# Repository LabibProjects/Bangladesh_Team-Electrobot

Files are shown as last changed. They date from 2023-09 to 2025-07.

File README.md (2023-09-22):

# Engineering materials | Team Electrobots | Bangladesh
----

This repository contains engineering materials of a self-driven vehicle's model participating in the WRO Future Engineers competition in the season 2023.

----
## Team Members:

- Zuniyed Hossain Bhuiyan
- L.M Mahir Labib
- Tanvir Rahman Saad
----

## Contents

* `t-photos` contains 2 photos of the team (an official one and one funny photo with all team members)
* `v-photos` contains 6 photos of the vehicle (from every side, from top and bottom)
* `video` contains the video.md file with the link to a video where driving demonstration exists
* `schemes` contains one or several schematic diagrams in form of JPEG, PNG or PDF of the electromechanical components illustrating all the elements (electronic components and motors) used in the vehicle and how they connect to each other.
* `src` contains code of control software for all components which were programmed to participate in the competition
* `models` is for the files for models used by 3D printers, laser cutting machines and CNC machines to produce the vehicle elements. If there is nothing to add to this location, the directory can be removed.
* `Mobility Management` contains details of the movement management of the bot, chasis design,power,torque etc.
* `Power and Sense Management` contains discussion about the power supply and sensors used in the vehicle.
* `Obstacle Management` include the strategy for the vehicle to negotiate the obstacle course for all the challenges.
* `other` is for other files which can be used to understand how to prepare the vehicle for the competition. It may include documentation how to connect to a SBC/SBM and upload files there, datasets, hardware specifications, communication protocols descriptions etc. If there is nothing to add to this location, the directory can be removed.
----
## Introduction 

The "Electrobot Autonomous Vehicle" project is an innovative endeavor that combines cutting-edge technologies to create a self-guided vehicle capable of intelligent navigation. This repository serves as a central hub for all essential files, documentation, and information related to the project.The project utilizes an ESP32-based development board known as the "JRC Board." This versatile and powerful board forms the foundation of the vehicle's control system.To enable advanced object recognition capabilities, the vehicle is equipped with a DFROBOT Gravity Huskylens, an AI-based camera. This camera plays a crucial role in identifying and interacting with objects in the vehicle's environment.The project incorporates an MPU-6050 gyroscope and accelerometer sensor. This sensor suite provides critical data for lap counting and monitoring angular velocity. The angular velocity measurements are given in millivolts per degree per second (mV/deg/s).

## Electric System design: 

We have choosed the parts very carefully after several hours of R&D

+ JRC Board: An ESP32 based development board (Made in Bangladesh)
+ Huskylens: Embedded Vision Sensor
+ DFROBOT URM09 Ultrasonic Sensors
+ 12v 100 RPM DC Geared Motor
+ MG-996R 10 kg Servo Motor
+ L298N Motor Driver
+ Mpu 6050 gyroscope sensor
+ 2x MP1584 Buck Converter
+ XL 4015 Boost Converter
+ 3s Lipo Battery 11.1v 

----
## Software Setup Procedure

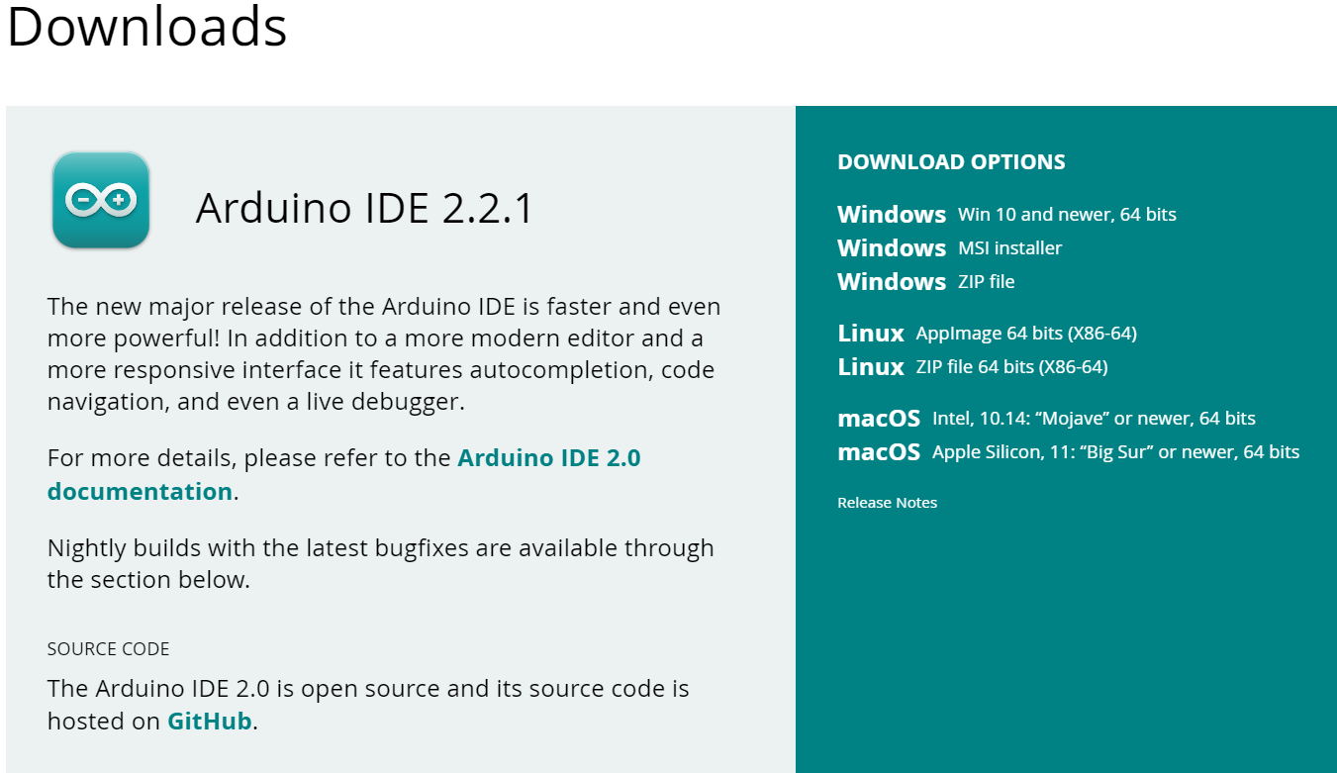
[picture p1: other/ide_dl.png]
ide_dl

- At first, we will have to download and install the most up-to-date version of the Arduino IDE on our computer. We can find the software at arduino.cc/en/Main/Software.

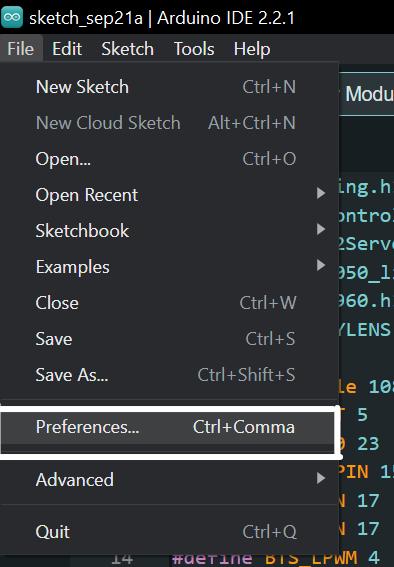
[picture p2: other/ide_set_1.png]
ide_set_1
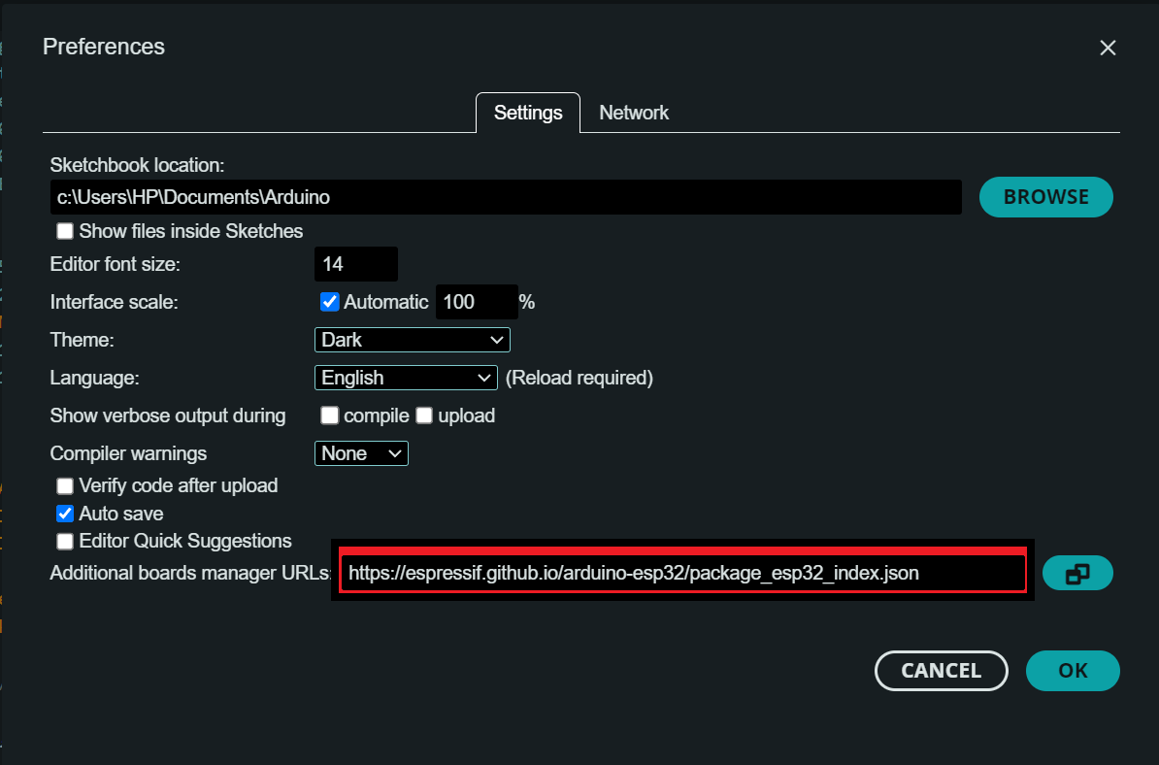
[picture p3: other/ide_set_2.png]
ide_set_2
   |  
- In our Arduino IDE, we need to go to File > Preferences, and then enter the following into the 'Additional Board Manager URLs' field. Finally, we click OK.
`https://espressif.github.io/arduino-esp32/package_esp32_index.json`

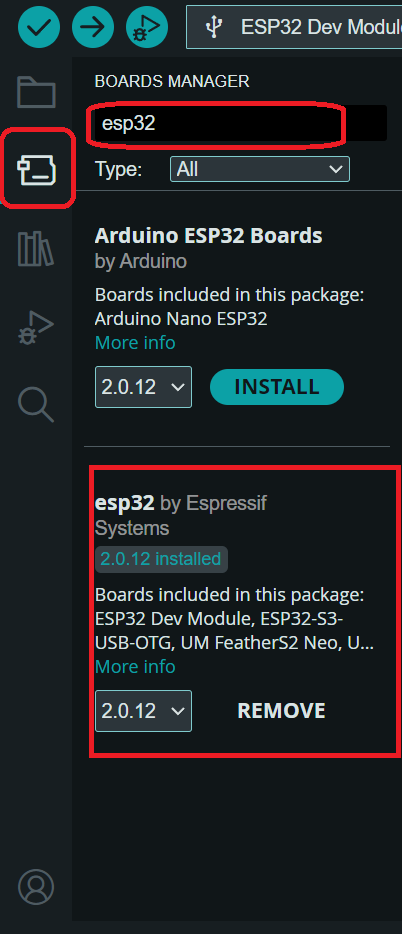
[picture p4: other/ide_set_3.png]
ide_set_3

- On the left side of our IDE we will have to open our Board Manager . Press install button for the "ESP32 by Espressif Systems".

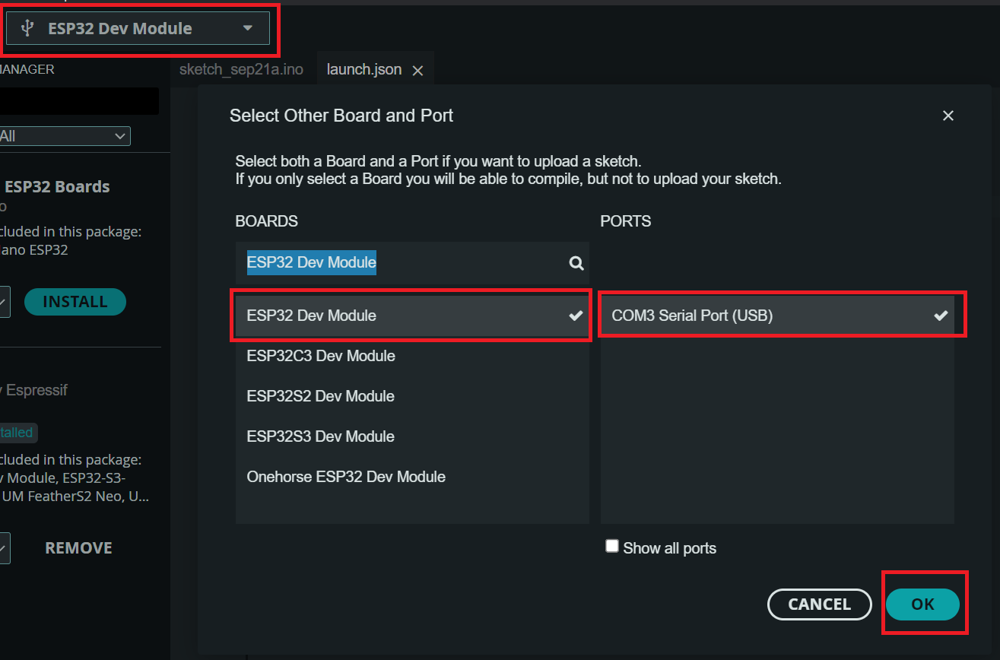
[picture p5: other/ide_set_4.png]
ide_set_4

- Now we will have to select our board so on the upper left side of IDE we will select our board, "ESP32 DEV MODULE" then we will select our prefered board where we have connected our JRC board.

ide_set_5
- Finally our task is to upload the code clicking "→" icon we upload our code. 

- Now we can turn on the toggle switch after placing robot on track and it will start doing the laps.

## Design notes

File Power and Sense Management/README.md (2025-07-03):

**Power and Sense Management**
====
In the realm of robotics, effective power and sense management is the linchpin of our robot's performance. Our cutting-edge system ensures optimal resource allocation, revolutionizing how robots interact with their surroundings.

## 1. Power Management: 

Power
">

   At first from lithium ion cell we are fetching 3.7v and being 12v by XL60009. then HW-411A LM2596 are cosuming power to 3.3v for the sensor e.g. Pi Camera, SR04 ultrasonic sensor and gyroscope MPU 6050.  Laterby we are suplying 5v to servo 12v to BTS7960 and motor being powered to.
## 2. Sensors: 
Sensor

- #### **Ultrasonic Sensor:**
   

   The SR04 is an ultrasonic distance sensor used for measuring distances. We're powering it with a stable 5V supply obtained from an HW-411A LM2596 voltage regulator connected to an 11.1V LiPo battery. This setup ensures reliable distance measurements and efficient power management for our robot.

- #### **Pi Camera:**
  

The Raspberry Pi Camera is a high-definition vision module capable of capturing images and streaming video, commonly used in robotics and computer vision applications. In our configuration, we use the Raspberry Pi Camera Module connected to a Raspberry Pi 4B, which serves as the core processing unit for advanced image processing tasks. The camera interfaces directly with the Raspberry Pi via the CSI (Camera Serial Interface) port, enabling high-speed data transfer. 
- #### **Gyroscope:**
  MPU

The MPU6050 is a popular gyroscope and accelerometer sensor used for motion sensing and orientation tracking in various applications, including robotics and motion-controlled devices. In our setup, the MPU6050 is powered by a 5V supply sourced from an ESP32 Dev Board, which itself receives power from an HW-411A LM2596 voltage regulator. This HW-411A LM2596 regulator is connected to an XL60009 module, and the entire system is powered by an 3.7V lithium ion cell.

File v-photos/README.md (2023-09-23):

Vehicle's photos
====

This directory must contain 6 photos of the vehicle (from every side, from top and bottom)

## File perspective description

   - `front.jpeg`: Front view: L298N motor driver, a battery unit and front steering axles.
   - `bottom.jpeg`: Bottom view: main motor functions
   - `top.jpeg`: Top view: PCB, JRC Board, huskylens, boost converter, gyroscope, sonar sensor and servo
   - `bottom.jpeg`: Bottom view: aluminium base plate
   - `left.jpeg`: Left view: Wheels and front steering axel from left perspective
   - `right.jpeg`: Right view: Wheels and front steering axel from left perspective

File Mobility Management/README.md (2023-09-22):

Mobility Management
====
In the realm of mobility management for our vehicle, we meticulously select and implement motors based on engineering principles like speed, torque, and power, while also considering chassis design and component mounting for optimal performance. Assembly instructions and 3D CAD files are available for easy part fabrication.

# Motor Selection and Implementation:
### 1. Motor Selection:
   - We carefully considered various factors like vehicle weight, desired speed, and torque requirements to make the right choice of motors. For our obstacle-avoiding bot, we opted for DC motors and servo motors to ensure precise control.
   - We performed calculations to determine the necessary torque, taking into account the bot's weight, wheel size, and the maximum slope it might encounter.
   - We also took into consideration the power supply and voltage requirements of the motors we selected.

### 2. Motor Controller:
   - We chose an appropriate motor controller, the BTS7960, to effectively control the motors.
   - We made sure that the motor controller was compatible with our microcontroller or control board.

### 3. Implementation:
   - We connected the motors to the motor controller and then linked the controller to the JRC Board.

# Chassis Design and Selection:
### 1. Chassis Material: Plastic with a steel alloy base.
### 2. Chassis Shape:
   - We designed the chassis to accommodate all the components, including motors, sensors, and the power source.
   - We ensured that the chassis provided adequate ground clearance and stability.

### 3. Mounting Components:
   - We carefully planned the layout of components on the chassis to ensure an even weight distribution and easy access for maintenance.
   - Subsequently, we securely mounted the motors, ultrasonic sensor, gyroscope, JRC booster, Husylens, and the power supply.

### 4. Engineering Principles:
   - We calculated the center of mass to maintain stability.
   - We took into account the wheelbase and track width to optimize maneuverability.
   - We paid attention to proper weight distribution to prevent tipping.

# Building and Assembly Instructions:
### 1. Step-by-Step Assembly:
   - We provided clear, step-by-step instructions for assembling the vehicle, starting from the chassis and moving on to component mounting.
   - Additionally, we included wiring diagrams to assist in connecting motors, sensors, and controllers.

### 2. 3D Printing Parts:
   - WE designed Sonar mount and wheels for better optimization in Auodesk Fusion360.
   - We also included instructions for printing these parts, specifying recommended materials and settings.

### 3. Testing and Calibration:
   - We explained how to calibrate the vehicle's sensors and motor controllers.
   - We provided guidance on testing the vehicle's basic movements and its ability to detect obstacles effectively.

### 4. Safety Considerations:
   - We emphasized safety precautions when working with motors, electronics, and power sources, ensuring that safety was a top priority throughout the project.

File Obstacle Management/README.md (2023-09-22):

Obstacle Management
====
To create a bot that can navigate a track with obstacles using an ultrasonic sensor and gyroscope, you'll need to implement a control algorithm that allows the bot to detect obstacles, stop when necessary, and navigate around them. Below is a high-level strategy along with some pseudo code to help you get started.
## **Strategy:**

1. Initialize the bot with the necessary sensors and gyroscope.
2. Start the bot and begin the first lap.
3. Continuously monitor the ultrasonic sensor to detect obstacles in the path.
4. Use the gyroscope to maintain the bot's direction and orientation.
5. When an obstacle is detected:
   - Determine the direction of the obstacle (left or right).
   - Turn the bot in the opposite direction to avoid the obstacle.
   - Resume forward movement once the obstacle is clear.
6. Continue navigating the track and detecting obstacles until completing three laps.

Additionally, we need to fine-tune the values and thresholds for obstacle detection and the turning angles based on your bot's characteristics and the track layout. Testing and iterating on the code and parameters will be crucial to ensure your bot successfully completes the laps while avoiding obstacles.

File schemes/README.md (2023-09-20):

Electrical Systems Design
====

Folder contains the electrical design schematics,pcb design,block diagram designed in EasyEDA and Altium Designer

## Description of Electrical Systems Design

   - `Schematic.pdf`: This is the schematic's pdf file, which is suitable for printing..
   - `PCB_3d_model.pdf`: This is the 3d version of the PCB, which helps understanding the I/O pinouts.
   - `PCB.pdf`: This is the pdf of the pcb.
   - `pcb_pinouts.png`: To help understanding the pinouts of the PCB.
   - `System_Management`: Diagram of the overall system.
   - `Block_Diagram`: Block Diagram of the system.

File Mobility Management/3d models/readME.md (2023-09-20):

Custom 3D Printed Design 
====
All of our robot's crucial components were created through 3D printing after being meticulously designed and modeled using Autodesk Fusion 360.

## Description of 3D Printable Files

   - `20 degree angled URM09 sonar mount.stl`: This model serves as a mounting solution for precisely positioning our front two URM09 sensors at a 20-degree angle.
   - `Front Wheel.stl`: To make turn more precisely we designed custom wheel .

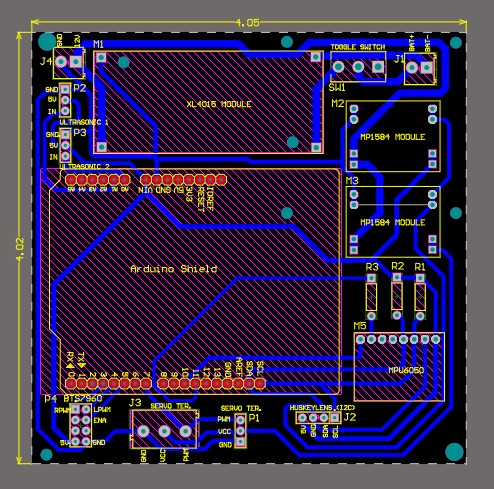
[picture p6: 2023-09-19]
schemes/pcb_pinouts.jpeg

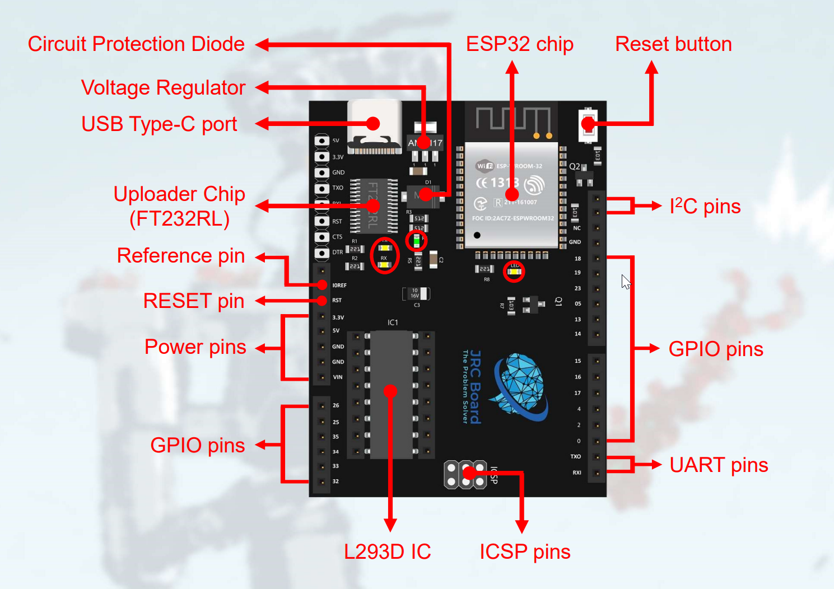
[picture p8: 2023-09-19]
schemes/JRC_board_pinouts.png

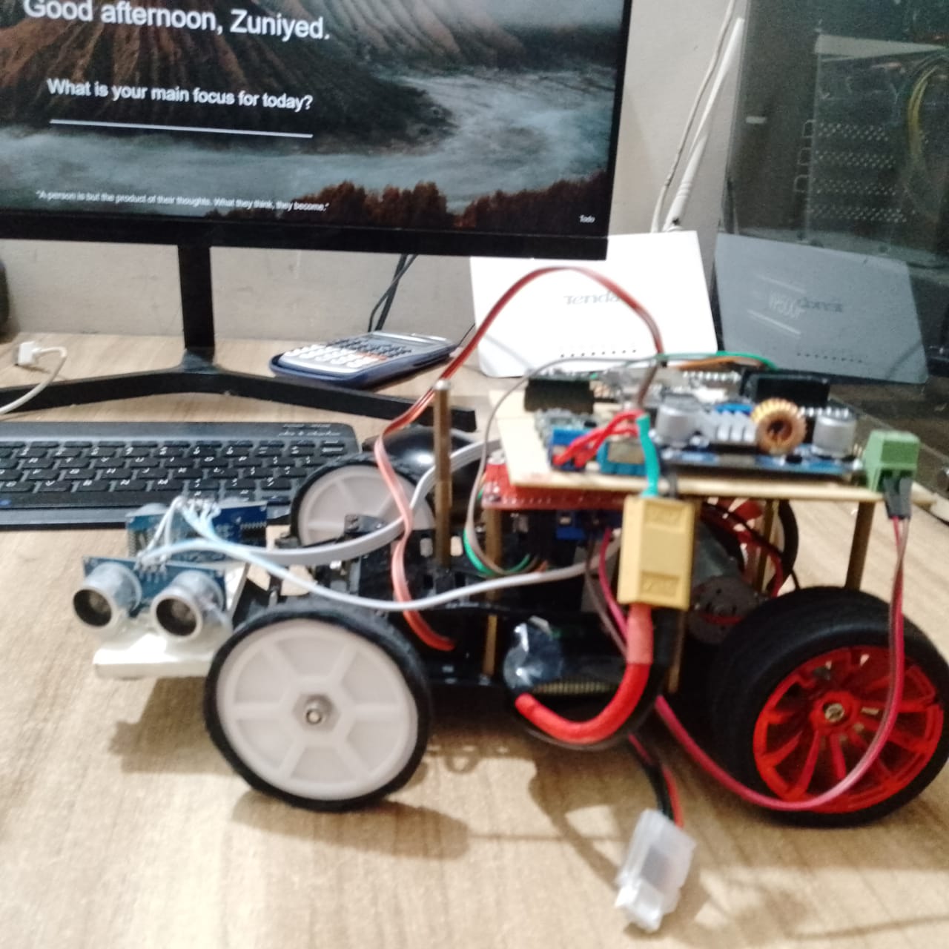
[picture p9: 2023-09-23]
v-photos/left.jpeg

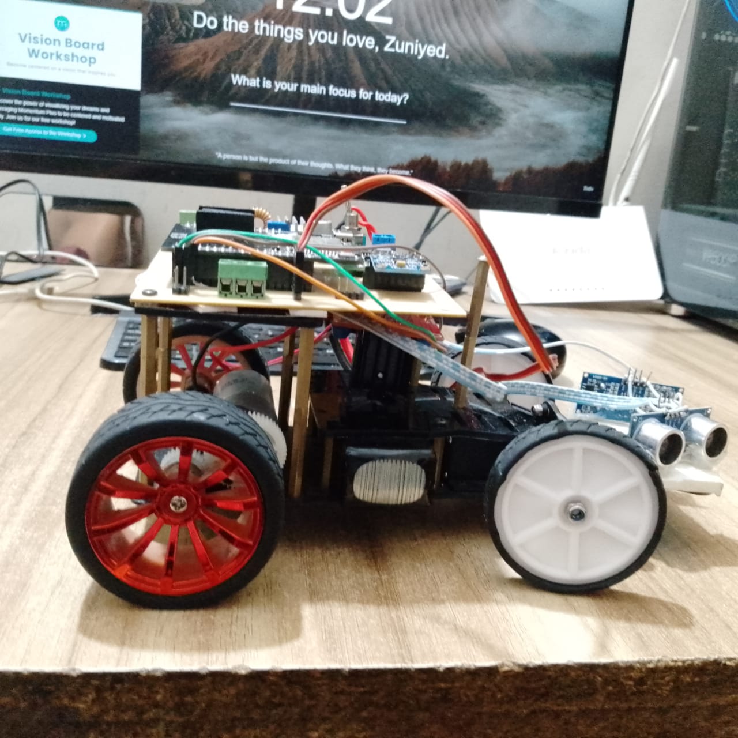
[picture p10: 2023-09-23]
v-photos/right.jpeg

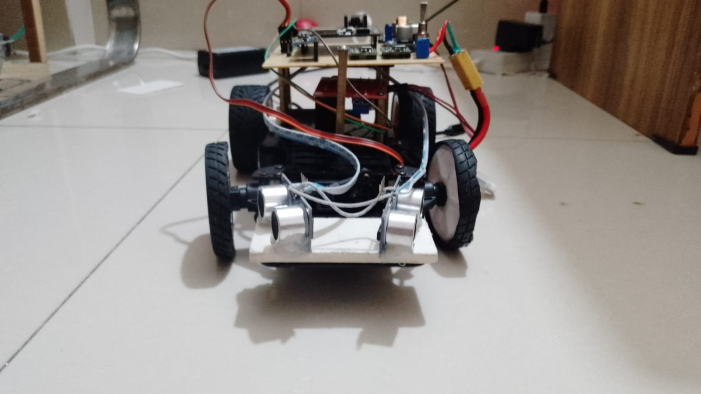
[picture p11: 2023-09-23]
v-photos/front.jpeg

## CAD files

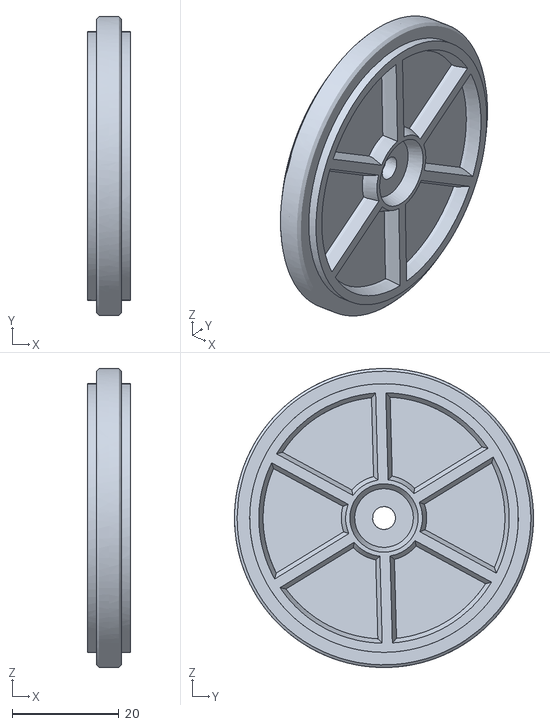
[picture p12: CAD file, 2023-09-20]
Mobility Management/3d models/Front Wheel.stl
8.00 x 56.0 x 56.0

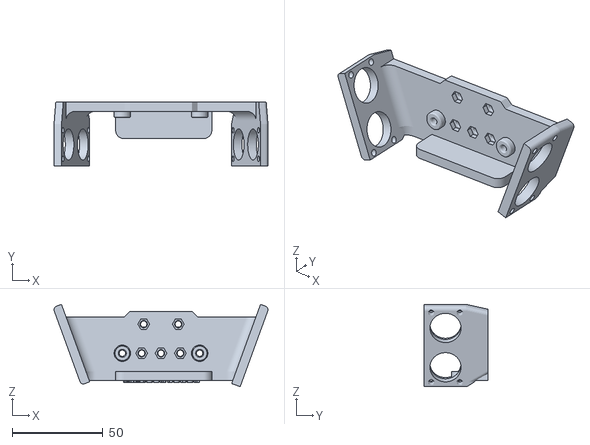
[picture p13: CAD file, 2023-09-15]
Mobility Management/3d models/20 degree angled URM09 sonar mount.stl
117.6 x 35.0 x 45.3

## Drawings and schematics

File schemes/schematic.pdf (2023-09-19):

Power Section | Sensors and Camera

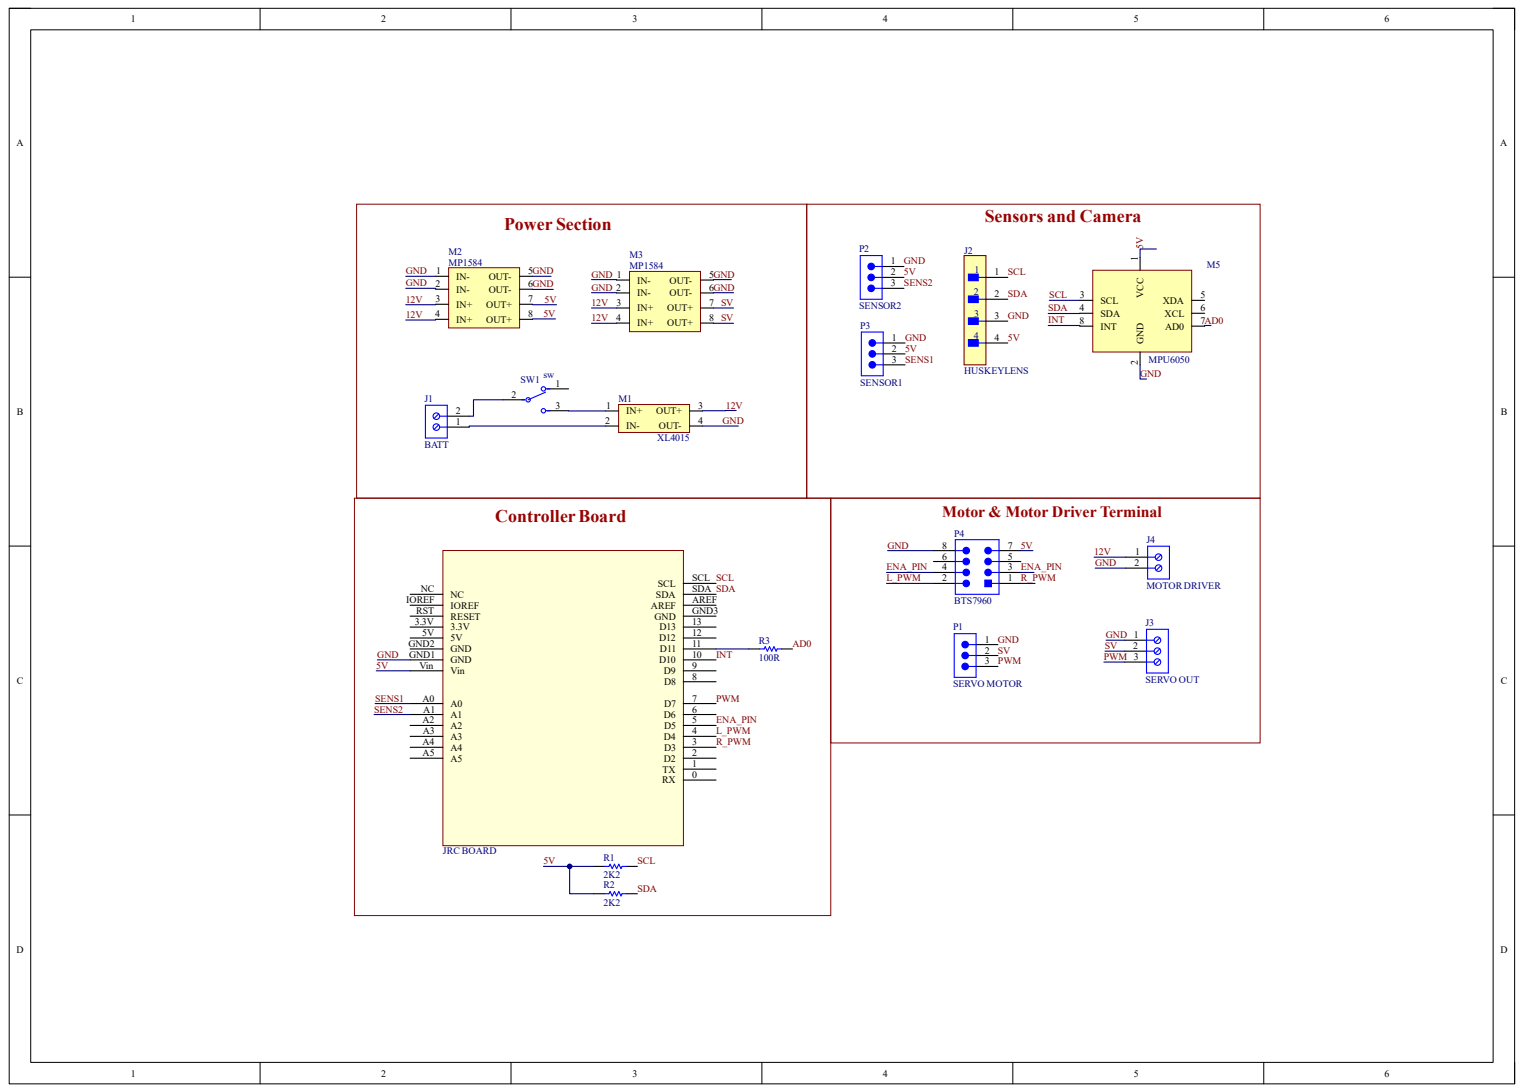
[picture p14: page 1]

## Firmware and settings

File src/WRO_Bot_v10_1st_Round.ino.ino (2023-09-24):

  #include "Wire.h"
  #include <MPU6050_light.h>
  #include <ESP32Servo.h>
  #include <NewPing.h>
  #include "HUSKYLENS.h"

  #define dbg 1
  #define turningAcceleration 8  //8
  #define distanceTolarance 8
  #define testClearance 44
  #define minClearance 40
  #define withThreshold 80
  #define narrowThreshold 35

  #define middlePos 70
  #define leftMax 40 //30 //20
  #define rightMax 100 //100 //120
  
  #define carSpeed 200
  #define turningDelay 500

  #define stopTime 2000
  #define endAngle 1030

  #define servoPin 15
  #define startSW 14

  #define rightSonarTrig 25  
  #define rightSonarEcho 26  
  #define leftSonarTrig 33
  #define leftSonarEcho 32
  #define maxDistance 200 // Maximum distance we want to ping for (in centimeters). Maximum sensor distance is rated at 400-500cm.

  #define mPin1 4
  #define mPin2 2
  #define enPin 17
  #define ledPin 13

  MPU6050 mpu(Wire);
  HUSKYLENS huskylens;

  Servo servo;  // create servo object to control a servo

  NewPing rightSonar(rightSonarTrig, rightSonarEcho, maxDistance);  // NewPing setup of pins and maximum distance.
  NewPing leftSonar(leftSonarTrig, leftSonarEcho, maxDistance);     // NewPing setup of pins and maximum distance.

  uint16_t leftSonarVal = 0, rightSonarVal = 0;
  uint16_t leftClearance = 0, rightClearance = 0, totalDistance = 0;
  int yawAngle = 0, rawYaw = 0;
  uint8_t startPosition = 1, lapsCount = 0;
  int pos = middlePos;
  bool gotMaxDistance = 0;
  int  tempLeftClearance = 0, tempRightClearance = 0;
  int currentTotalWidth = 0;
  bool narrowImportant = 0;
  bool blue =0, orange = 0, colorStts = 1;
  uint8_t color = 0;
  unsigned long currentTime = 0, prevTime = 0;
  unsigned long currentTime2 = 0, prevTime2 = 0;
  bool lapStts = 0;

  void setup() {
    if(dbg) Serial.begin(115200);
    
    mpuInit();

    servo.attach(servoPin);  // attaches the servo on pin 9 to the servo object
    servo.write(middlePos);
    delay(200);

    pinMode(mPin1, OUTPUT); pinMode(mPin2, OUTPUT);
    pinMode(enPin, OUTPUT); pinMode(ledPin, OUTPUT);
    pinMode(startSW, INPUT_PULLUP);
    digitalWrite(mPin1, 0); digitalWrite(mPin2, 0); digitalWrite(enPin, 0);

    calculateClearance();
    HuskyInit();

    while(digitalRead(startSW)){ 
      digitalWrite(ledPin, 0); delay(100);
      digitalWrite(ledPin, 1); delay(100);
      }
    forward(carSpeed);
  }

  void loop() {
    leftSonarVal = leftSonar.ping_cm(); 
    rightSonarVal = rightSonar.ping_cm();
    currentTotalWidth = leftSonarVal + rightSonarVal;

    color = getHusky();

    if(leftSonarVal < 5 || leftSonarVal > 100) { leftSonarVal = maxDistance; } 
    if(color == 1) {
      if(gotMaxDistance == 0 ) {
         gotMaxDistance =1; startPosition = 0; 
         if(leftClearance > narrowThreshold) narrowImportant = 1;
        } 
      }
    if(rightSonarVal < 5 || rightSonarVal > 100) { rightSonarVal = maxDistance;}
    if(color == 10) {
        
       if(gotMaxDistance == 0 ) {
         gotMaxDistance =1; startPosition = 1; 
         if(rightClearance > narrowThreshold) narrowImportant = 1;
        }
      } 

    if(narrowImportant){
      if (currentTotalWidth < withThreshold){
        tempLeftClearance = minClearance/2;
        tempRightClearance = minClearance/2; 
      }
      else if ( (currentTotalWidth > withThreshold) && (currentTotalWidth < 110) ) {
        tempRightClearance = minClearance;
        tempLeftClearance = minClearance;
      }
    }

         if ( startPosition == 0) { stayLeft2(tempLeftClearance);  } 
    else if ( startPosition == 1) { stayRight2(tempRightClearance);}

    lapsCheck2(3);
    
    if(dbg) debug();
    digitalWrite(ledPin, lapStts);
  }




////////////////// Function ///////////////////////


uint8_t getHusky() {
  blue = 0; orange = 0;
  huskylens.request(1); blue = huskylens.count(1);
  huskylens.request(2); orange = huskylens.count(2);
  // Serial.print(blue); Serial.print(" ");
  // Serial.print(orange); Serial.println(" ");

  return (blue + orange*10);
}

void HuskyInit(){
  while (!huskylens.begin(Wire)) {
    Serial.println(F("Begin failed!"));
    Serial.println(F("1.Please recheck the \"Protocol Type\" in HUSKYLENS (General Settings>>Protocol Type>>I2C)"));
    Serial.println(F("2.Please recheck the connection."));
    delay(100);
  }
}
void HuskyLens_Test() {
  if (!huskylens.request()) Serial.println(F("Fail to request data from HUSKYLENS, recheck the connection!"));
  else if (!huskylens.isLearned()) Serial.println(F("Nothing learned, press learn button on HUSKYLENS to learn one!"));
  else if (!huskylens.available()) Serial.println(F("No block or arrow appears on the screen!"));
  else Serial.println(F("HuskyLens OK!!!"));
}

void debug(){
    Serial.print(leftSonarVal); Serial.print("  cm    R:  ");
    Serial.print(rightSonarVal); Serial.print("  cm  ");
    // Serial.print("  yaw main : "); Serial.print(yawAngle);
    // Serial.print("  Laps: "); Serial.print(lapsCount);
    Serial.print("  lCL: "); Serial.print(leftClearance);
    Serial.print("  rcl: "); Serial.print(rightClearance);
    Serial.print("  NI: "); Serial.print(narrowImportant);
    Serial.print("  TW: "); Serial.print(currentTotalWidth);
    Serial.print("  stPos: "); Serial.print(startPosition);
    Serial.print("  Pos: "); Serial.print(pos);
    Serial.print("  clr: "); Serial.print(color);

    Serial.println("");
    }



void lapsCheck2(uint8_t noLaps) {
  mpu.update();
  yawAngle = abs(mpu.getAngleZ())  ;
  //Serial.print(yawAngle);
  rawYaw = yawAngle;

  currentTime = millis();
  
  if( rawYaw > endAngle ){  // 1030

    if( colorStts &&  (startPosition == 0 && color == 10) || (startPosition == 1 && color == 1))  {

      colorStts =0;  lapStts = !lapStts;
      prevTime2 = currentTime; 
      }
    
    if( (currentTime - prevTime) > 300 ){
      colorStts = 1;
      prevTime = currentTime; 
      // Serial.println("color reset"); delay(500);
    }
  
     if( (currentTime - prevTime2) > stopTime ){
    stop(); while(9);
  }  
     
     }
}


void forward(byte speed) {
    // analogWrite(enPin, speed);
    digitalWrite(enPin, 1); 
    // digitalWrite(mPin1, 0); digitalWrite(mPin2, 1);
    digitalWrite(mPin1, 0); analogWrite(mPin2, speed);
    //Serial.println("forward");

  }

void stop() {
  // analogWrite(enPin, speed);
  digitalWrite(enPin, 0); 
  // digitalWrite(mPin1, 0); digitalWrite(mPin2, 1);
  digitalWrite(mPin1, 0); analogWrite(mPin2, 0); delay(500);
}


void mpuInit() {
  Wire.begin();

  byte status = mpu.begin();
  // Serial.print(F("MPU6050 status: "));
  // Serial.println(status);
  while (status != 0) {}  // stop everything if could not connect to MPU6050

  // Serial.println(F("Calculating offsets, do not move MPU6050"));
  delay(1000);
  // mpu.upsideDownMounting = true; // uncomment this line if the MPU6050 is mounted upside-down
  mpu.calcOffsets();  // gyro and accelero
  // Serial.println("Done!\n");
}


  void stayLeft2(uint16_t clearance){
    
     if ( (clearance + distanceTolarance)  < leftSonarVal ) { pos -= turningAcceleration; } // go left
    else if( clearance  < leftSonarVal ) { pos = middlePos - turningAcceleration; } // go left
    
    else if( (clearance - distanceTolarance) > leftSonarVal ) { pos += turningAcceleration; } // go right
    else if( clearance > leftSonarVal ) { pos = middlePos + turningAcceleration; } // go right
    else pos = middlePos;
         if( pos < leftMax) pos = leftMax;
    else if( pos > rightMax) pos = rightMax;
    servo.write(pos);
    
  }
  void stayRight2(uint16_t clearance){
    
    
     if ( (clearance + distanceTolarance)  < rightSonarVal ) { pos += turningAcceleration; } // go right
    else if( clearance  < rightSonarVal ) { pos = middlePos + turningAcceleration; } // go right
    
    else if( (clearance - distanceTolarance) > rightSonarVal ) { pos -= turningAcceleration; } // go left
    else if( clearance > rightSonarVal ) { pos = middlePos - turningAcceleration; } // go left
    else pos = middlePos;
         if( pos < leftMax) pos = leftMax;
    else if( pos > rightMax) pos = rightMax;
    servo.write(pos);
    
  } 

void calculateClearance(){
  digitalWrite(ledPin, 1);
  leftClearance = 0; rightClearance = 0;
  for (int i =0; i< 10; i++){
    leftClearance += leftSonar.ping_cm(); //delay(25);
    rightClearance += rightSonar.ping_cm(); //delay(25);
    
  }
  leftClearance /= 10;
  rightClearance /= 10;
  if( leftClearance > rightClearance){
    startPosition = 1; // 1 is for right
  }
  else {
      startPosition = 0; // 1 is for left
  }

  // digitalWrite(ledPin, startPnarrowImportantosition);
  if( leftClearance < minClearance ) leftClearance = minClearance;
  if( rightClearance < minClearance ) rightClearance = minClearance;
  
  tempLeftClearance = leftClearance;
  tempRightClearance = rightClearance; 

}

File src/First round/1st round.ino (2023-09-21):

#include <NewPing.h>
#include <PIDController.h>
#include <ESP32Servo.h>
#include <MPU6050_light.h>
#include <BTS7960.h>
#include <HUSKYLENS.h>

#define endAngle 1080  //3 laps
#define MPU_INT 5
#define MPU_AD0 23
#define SERVO_PIN 15
#define BTS_REN 17
#define BTS_LEN 17
#define BTS_LPWM 4
#define BTS_RPWM 2

#define MAX_DISTANCE 200 
#define ULTRA_RPIN 26
#define ULTRA_LPIN 25

#define clockwise 1
#define anticlockwise 0

///////////////////////////////////////////////////////////////////////

int yawAngle = 0, startAngle = 0;

unsigned long DisTimer = 0, MPUtimer = 0, lapTimer = 0;

int mainSpeed = 120;
bool start = false;
long LD, RD;
char dir;
int ID1 = 1;
//void Get_yawAngle();
///////////////////////////////////////////////////////////////////////
MPU6050 mpu(Wire);
Servo myservo;
HUSKYLENS huskylens;
NewPing sonarR(ULTRA_RPIN, ULTRA_RPIN, MAX_DISTANCE), sonarL( ULTRA_LPIN,  ULTRA_LPIN, MAX_DISTANCE);    
BTS7960 motor1(BTS_LEN, BTS_REN, BTS_LPWM, BTS_RPWM);   //This method will create a object of the class BTS7960

void setup () {
  Serial.begin(115200);  // Some methods require the Serial.begin() method to be called first'

  Wire.begin();
  while (mpu.begin() != 0) {
    Serial.print(F("MPU6050 failed to initialize!"));
  }
  mpu.calcOffsets(); // gyro and accelero
  lapTimer = millis();
  while (!huskylens.begin(Wire))
  {
    Serial.println(F("Begin failed!"));
    Serial.println(F("1.Please recheck the \"Protocol Type\" in HUSKYLENS (General Settings>>Protocol Type>>I2C)"));
    Serial.println(F("2.Please recheck the connection."));
    delay(100);
  }

  myservo.attach(SERVO_PIN);
  myservo.write(90); // 50, 90, 140
  motor1.begin();                           //This method will set the motor driver pins as output
  motor1.enable();                          //This method will set the L_EN and R_EN to HIGH or digitalWrite them to +5v/3v depending on your mcu

  motor1.pwm = 70;
  motor1.front();
  Rotate(20, clockwise);
  Get_yawAngle();
  start = true;
}

int endAngleReached = 0;

void loop () {
  Get_Distance();
  Get_yawAngle();
  HuskyLens_Test();
  if (yawAngle > endAngle - 18 && yawAngle < endAngle + 18) {
    endAngleReached++;
    Serial.println(String() + F("Lap: ") + endAngleReached );
    if( endAngleReached == 3 ) {
        motor1.stop();
        Rotate(0, anticlockwise);
        Serial.println( F("Goal Line") );
    }
  }


}
///////////////////////   Rotate    ////////////////////
void Rotate(int angle, int dir ) {
  if( dir == clockwise ) angle += 90;
  else angle = 90 - angle;
  myservo.writeMicroseconds(angle);
}

///////////////////////   HuskyLens Test    ////////////////////
void HuskyLens_Test() {
  if (!huskylens.request(ID1)) Serial.println(F("Fail to request data from HUSKYLENS, recheck the connection!"));
  else if(!huskylens.isLearned()) Serial.println(F("Nothing learned, press learn button on HUSKYLENS to learn one!"));
  else if(!huskylens.available()) Serial.println(F("No block or arrow appears on the screen!"));
  else Serial.println(F("HuskyLens OK!!!"));
}

///////////   Get Left and Right Distance per 50ms ///////////////
void Get_Distance() {
    if( millis() - DisTimer > 50) {
      LD = sonarL.ping_cm();    
      RD = sonarR.ping_cm();
      Serial.println( String() + F("LeftDistance = ") + LD);
      Serial.println( String() + F("RightDistance = ") + RD);
      DisTimer = millis();
    }    
}

////////////////////   Get yawAngle per 50 ms ////////////////////
void Get_yawAngle() {
  mpu.update();
  if ((millis() - MPUtimer) > 50) {
    if (start == false) {
      startAngle = abs(mpu.getAngleZ());
      Serial.println(startAngle);
    } else {
      yawAngle = abs(mpu.getAngleZ()) - startAngle;
      Serial.println( String() + F("YawAngle = ") + startAngle);
    }
    MPUtimer = millis();
  }
}
